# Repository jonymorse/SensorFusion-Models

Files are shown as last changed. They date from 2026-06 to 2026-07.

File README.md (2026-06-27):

# Sensor Fusion Models

ForgeCAD models and supporting scripts for the sensor fusion project's 3D
design work.

## Layout

```text
cad/
  sensor_fusion/  Active sensor fusion, PT3, GoPro, and RealSense CAD sources
  calibration/    Active thermal calibration target CAD source
  tests/          Printable fit/check coupons and their local helpers
  concepts/       Older concepts and exploratory designs

hardware_refs/    Imported STEP/F3D/3MF reference geometry
docs/             Design notes and requirements
outputs/
  previews/       Rendered preview images
  exports/        Generated CAD exports
archive/          Historical reports, tiny experiments, and superseded sources
scripts/          Utility scripts for snap-fit tuning workflows
```

`forgecad_work_2026-06-22/references/` is intentionally ignored. It is a local
copied reference bundle, not part of the cleaned source tree.

## Commands

```powershell
npm.cmd run check:coupon
npm.cmd run check:insert-coupon
npm.cmd run check:thermal
npm.cmd run check:realsense
npm.cmd run check:sensor-fusion
npm.cmd run check:gopro-stand
npm.cmd run studio
```

PowerShell script execution is disabled on this machine, so use `npm.cmd` and
`forgecad.cmd` rather than the `.ps1` shims.

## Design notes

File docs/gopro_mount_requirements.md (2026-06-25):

# GoPro-Compatible Mount Requirements

## Scope

Design a new, 3D-printable GoPro-compatible mount without modifying the thermal
calibration target. The first interface should be the accessory-side 3-prong
receiver that accepts the two folding fingers on a GoPro camera.

GoPro confirms that its ecosystem uses standard mounting fingers and offers
adapters between mounting fingers and 1/4-20 equipment, but GoPro does not
publish a dimensioned finger-interface drawing.

Official references:

- https://gopro.com/en/pl/shop/mounts-accessories/mounting-finger-adapter/ABTFR-001.html
- https://gopro.com/en/at/shop/mounts-accessories/tripod-adapters/ABQRT-003.html

The dimensions below are de facto compatibility dimensions cross-checked from
measured examples and a parametric OpenSCAD implementation. They are not an
official GoPro mechanical standard.

Measured and parametric references:

- https://www.instructables.com/GoPro-clamp-mount-for-multiple-angles-with-one-cam/
- https://github.com/ridercz/GoProScad/blob/master/GoPro.scad

## Interface Datasheet

| Feature | Nominal | First-print target | Notes |
|---|---:|---:|---|
| Finger thickness | 3.0 mm | 3.0 mm | Both 2-prong and 3-prong fingers |
| Mating gap | 3.5 mm | 3.4-3.5 mm | Includes practical print clearance |
| Pivot screw | M5 | M5 x 0.8 | Original GoPro thumb screw preferred |
| Pivot hole | 5.0 mm | 5.3 mm | Tune from 5.1-5.5 mm by test print |
| Rounded finger-end diameter | 15.0 mm | 15.0 mm | Radius 7.5 mm |
| Finger/leg height | 17.0 mm | 17.0 mm | Do not reduce below 15 mm |
| Base thickness | 3.0 mm | 3.5-4.0 mm | Increased for FDM strength |
| Minimum mount width | 15.0 mm | 20.0 mm | Width perpendicular to finger stack |
| 2-prong stack depth | 9.5 mm | 9.5 mm | 3 + 3.5 + 3 |
| 3-prong interface depth | 16.0 mm | 16.0 mm | 3 + 3.5 + 3 + 3.5 + 3 |
| Nut-capture allowance | 3.0 mm | Optional | Raises 3-prong base depth to 19 mm |

For a 17 mm leg and 3 mm base, the pivot axis is 12.5 mm above the bottom of
the base, or 9.5 mm above the base's top face.

## Parametric Controls

The ForgeCAD model should expose these controls:

- `Interface`: 3-prong receiver or 2-prong arm.
- `Finger Thickness`: default 3.0 mm, range 2.8-3.2 mm.
- `Mating Gap`: default 3.5 mm, range 3.2-3.8 mm.
- `Pivot Hole Diameter`: default 5.3 mm, range 5.0-5.6 mm.
- `Finger Height`: default 17 mm, range 15-22 mm.
- `Base Width`: default 20 mm, minimum 15 mm.
- `Base Thickness`: default 4 mm, minimum 3 mm.
- `Nut Capture`: none, square M5 nut, or hex M5 nut.

Do not scale the entire interface uniformly. Finger width, mating clearance,
and pivot-hole clearance need independent tolerances.

## Structural Requirements

- Add at least a 2 mm root fillet or equivalent tapered gusset at each finger.
- Keep at least 2.0 mm of material around the pivot hole.
- Avoid sharp internal corners at the finger-to-base transition.
- Use the original metal M5 thumb screw rather than a printed screw.
- Add a mechanical safety tether for vehicle, helmet, overhead, or outdoor use.
- Keep the camera center of mass as close to the pivot as the application allows.
- Treat the mount as a prototype until it passes fit, torque, vibration, and drop tests.

## Bambu A1 Print Requirements

- PLA+ is acceptable for fit prototypes; PETG or ASA is preferred for outdoor,
  hot-car, vibration, or impact exposure.
- Use a 0.4 mm nozzle with at least four walls/perimeters.
- Use 0.16-0.20 mm layers around the interface.
- Use at least 40% infill; use more for long arms or high-vibration mounts.
- Orient the part so layer lines run along the finger length, not across the
  finger roots. Side printing will usually require support but is stronger.
- Avoid aggressive cooling on PETG/ASA finger roots to preserve layer adhesion.

## Validation Coupon

Before printing the full mount, print a coupon containing only:

- The 3-prong finger interface.
- A 5.3 mm through-hole.
- One 3.4 mm gap and one 3.5 mm gap option.
- The 15 mm rounded finger ends.

Acceptance criteria:

- Camera fingers insert by hand without forcing or visible spreading.
- The M5 thumb screw passes through without drilling.
- The joint clamps firmly and holds angle without wobble.
- Fingers show no whitening, cracking, or delamination after ten clamp cycles.
- The camera can be removed without tools other than the normal thumb screw.

## Decisions Needed Before Full Geometry

- Base attachment: flat screw-down plate, adhesive base, clamp, 1/4-20 socket,
  tripod adapter, or custom device interface.
- Camera model and expected payload.
- Required tilt range and whether the joint must rotate continuously.
- Indoor prototype or outdoor/action use.
- Original GoPro thumb screw or generic M5 hardware.

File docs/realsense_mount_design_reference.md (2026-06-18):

# RealSense Mount Design Reference

This document is the measurement and packaging reference for the redesigned
RealSense / PureThermal / USB-C hub mount.

It is meant to answer two questions before CAD work starts:

1. What hardware is definitely part of the assembly?
2. What dimensions are confirmed vs. still need to be measured?

## Assembly Scope

Current known components:

- Intel RealSense Depth Camera `D435i`
- PureThermal 3 FLIR Lepton Smart I/O Board
- ORICO USB-C hub PCB from the `ORICO-XHJ2U2C-G2`
- Optional rear mounting interface
  - original design: GoPro-style prongs
  - current alternate mode: stand legs

## Confirmed Dimensions

### Intel RealSense D435i

Source status: `confirmed from official Intel / RealSense documentation`

| Item | Value | Notes |
| --- | --- | --- |
| Overall width | `90 mm` nominal | D435 / D435i body width |
| Overall height | `25 mm` nominal | cross-section height |
| Overall depth | `25 mm` nominal | housing depth |
| Weight | `72 g` in 2018 datasheet, `75 g` in later RealSense datasheet | small revision difference between source editions |
| Mounting holes | `2x M3` | mechanical drawing calls out `2X M3 mounting point` |
| Max screw insertion depth | `3 mm` | called out in mechanical drawing |
| Mount hole spacing | `45 mm` | center-to-center spacing shown in the mechanical drawing top view |
| Stereo baseline | `50 mm` | useful reference, but not the mount-hole spacing |
| IMU | `6DoF` | D435i-specific feature |
| Depth FOV (HD) | `87 deg x 58 deg` | from product family table |

### D435i Mounting Notes

- Use `M3` screws only for the D435i mount points.
- Treat `3 mm` as the maximum safe thread engagement into the camera body.
- The `45 mm` value is the relevant bracket dimension for the two camera mount
  points.
- The `50 mm` value shown in the mechanical drawing is the stereo baseline, not
  the screw-hole spacing.
- Rear USB-C cable clearance must be preserved in the final bracket layout.

### PureThermal 3 FLIR Lepton Smart I/O Board

Source status: `confirmed from official GroupGets datasheet / mechanical drawing`

| Item | Value | Notes |
| --- | --- | --- |
| Overall board width | `25.8 mm` | mechanical drawing |
| Overall board height | `28.9 mm` | mechanical drawing |
| Mounting holes | `4` | one near each rounded corner |
| Mounting hole diameter | `2.2 mm` | drawing callout `diameter 2.2` |
| Mounting hole X spacing | `20.7 mm` | center-to-center from left to right mounting holes |
| Mounting hole Z spacing | `23.9 mm` | center-to-center from top to bottom mounting holes |
| Board tolerance | `+/- 0.2 mm` | stated on the mechanical drawing |
| Board thickness / section reference | `1.6 mm` | shown on side-view drawing; interpreted as PCB thickness |
| USB connector | `USB-C` | edge-mounted on one side of the board |
| Breakout edges | `0.1 in / 2.54 mm` pitch through-holes | per datasheet feature list |

### PureThermal 3 Mounting Notes

- The corner mounting pattern is much smaller than the D435i pattern, which
  means the PureThermal 3 can likely fit well inside the D435i mounting-height
  envelope.
- The mounting holes are `2.2 mm`, so they are suited to approximately `M2`
  class hardware or clearance around similarly sized fasteners.
- The board includes an edge-mounted `USB-C` connector and side breakout rows,
  so the bracket should avoid trapping cable insertion or access to edge I/O.
- The Lepton socket occupies the central top-face area, so front-side keep-outs
  around the sensor module and its viewing path are important.

### ORICO USB-C Hub PCB

Source status: `exact product identified; external enclosure confirmed from official ORICO documentation; bare PCB dimensions provided from direct user measurement and redesign notes`

Exact product in use:

- Retail description: `ORICO 10Gbps USB-C Hub, 4-Port Zinc Alloy USB 3.2 Splitter with 2 USB-A & 2 USB-C Ports`
- Official ORICO model: `ORICO-XHJ2U2C-G2`

Confirmed external product details:

| Item | Value | Notes |
| --- | --- | --- |
| Product model | `ORICO-XHJ2U2C-G2` | official ORICO page |
| Housing material | `Zinc Alloy + PC` | official ORICO page |
| Input | `USB-C` | official ORICO page |
| Outputs | `2x USB-A, 2x USB-C` | official ORICO page |
| Transfer rate | `10 Gbps` | official ORICO page |
| Cable | `USB-C to USB-C, 0.5 m / 1 m` | official ORICO page |
| External housing size | `56.9 x 56.9 x 20.7 mm` | official ORICO page |
| Alternate retail size listing | `2.24 x 2.24 x 0.81 in` | Amazon listing; effectively the same size after unit conversion |

Confirmed PCB and mounting details:

| Item | Value | Notes |
| --- | --- | --- |
| PCB size | `51.0 x 51.0 mm` | from direct measurement / redesign notes |
| PCB thickness | `~1.6 mm` | from direct measurement / redesign notes |
| Mounting holes | `4` | one near each corner |
| Hole diameter | `2.4 mm to 2.6 mm` measured | design assumption `2.5 mm` |
| Hole center inset from edges | `~4.0 mm` | measured `~3.94 mm`, use `4.0 mm` for CAD |
| Hole spacing | `43.0 x 43.0 mm` | center-to-center |
| Hole centers | `(4,4), (47,4), (4,47), (47,47)` mm | using lower-left board corner as origin |
| Recommended PCB pocket | `51.8 x 51.8 mm` | includes clearance |
| Pocket clearance per side | `~0.4 mm` | from redesign notes |

### ORICO USB-C Hub Mounting Notes

- The official `56.9 x 56.9 x 20.7 mm` dimension is for the complete hub
  enclosure, not the bare PCB.
- The bare PCB is now dimensioned well enough to drive CAD for a replacement
  bottom shell or bracket interface.
- The hub has one upstream `USB-C` input and four downstream ports, so
  connector orientation and cable bend relief will be major layout drivers.
- A `51.8 x 51.8 mm` support pocket with `0.4 mm` clearance per side is the
  current recommended starting point.
- The replacement bottom shell should preserve the original screw geometry, port
  alignment, and PCB orientation so the stock clear top cover still fits.

## Needs Measurement

These items are part of the design, but I do not yet have every packaging
detail confirmed in-repo.

### USB-C PCB Hub

Still useful to confirm during shell redesign:

- boss/standoff height required to match the original enclosure stack
- exact screw head diameter and recess depth
- connector keep-out zones relative to the bare PCB
- solder-joint and underside component clearance depth
- whether the custom bottom shell should fully guard the sides or stay minimal

## Design Implications From Current Data

### D435i

- The camera is not the main height driver by itself; at `25 mm` tall it is
  relatively compact.
- The `45 mm` mount-hole spacing is close to the current CAD model's `45 mm`
  assumption, which is a good sign.
- Because the screw spec is `M3` with only `3 mm` max insertion depth, the
  bracket should avoid deep engagement assumptions or long screws bottoming out.

### PureThermal 3

- The PureThermal 3 board is small enough that it should not drive the overall
  mount height by itself.
- Its `20.7 mm x 23.9 mm` hole pattern makes screw-mounting much more attractive
  than long retainer rails.
- Because the board is only `25.8 mm x 28.9 mm`, it should be possible to place
  it within the same vertical envelope as the D435i mounting zone if desired.
- The `USB-C` edge and Lepton optical path should be treated as hard keep-out
  zones when shaping guards or protective walls.

### ORICO USB-C Hub

- The official product envelope is only moderately smaller than the current
  plate width, so this hub may still be one of the main packaging drivers.
- The measured `51.0 x 51.0 mm` PCB with a `43.0 mm` square hole pattern is now
  specific enough to support a proper shell redesign.
- This is the part most likely to determine whether the redesign uses
  screw-mounted shell capture, a pocketed cradle, or a guarded clamp strategy.

### Overall Mount Strategy

Because the D435i, PureThermal 3, and ORICO hub PCB all now have usable
mounting references, the redesign should strongly consider:

- screw-mounted boards instead of long rail retainers
- explicit standoffs or bosses
- controlled cable-clearance zones
- a separate decision about whether the GoPro interface is integrated or modular

## Open Questions

- Which exact PureThermal 3 board revision are we mounting?
- What boss/standoff height is required to reproduce the original ORICO shell's
  PCB stack-up under the reused clear top cover?
- What are the exact connector keep-out zones on the ORICO PCB relative to the
  mounting-hole origin?
- Should the GoPro-style rear interface be built into the main bracket or become
  a removable secondary part?
- Is the preferred redesign priority `smallest`, `cleanest`, `most rugged`, or
  some mix of those?

## Sources

- Intel RealSense D400 Series datasheet:
  https://cdrdv2-public.intel.com/841984/Intel-RealSense-D400-Series-Datasheet.pdf
- RealSense D435i product page:
  https://realsenseai.com/products/depth-camera-d435i/
- RealSense D400 Series datasheet, later revision:
  https://www.realsenseai.com/wp-content/uploads/2023/10/Intel-RealSense-D400-Series-Datasheet-September-2023.pdf
- GroupGets PureThermal 3 product page:
  https://groupgets.com/products/purethermal-3
- GroupGets PureThermal 3 datasheet:
  https://media.digikey.com/pdf/Data%20Sheets/GroupGets%20PDFs/PURETHERMAL-3_Rev2_Oct2022.pdf
- SparkFun PureThermal 3 listing:
  https://www.sparkfun.com/purethermal-3-flir-lepton-smart-i-o-board.html
- ORICO product page for the compact zinc alloy hub:
  https://www.orico.cc/index/product/detail/3473.html
- Amazon listing matching the retail description:
  https://www.amazon.com/ORICO-Splitter-High-Speed-Extender-Desktops/dp/B0FDB3WV1K
- Newegg listing with the matching ORICO model:
  https://www.newegg.com/p/0J2-001S-001Z6

## Source Notes

- Overall D435i body dimensions come from the D400 Series datasheet mechanical
  dimensions table.
- The `2x M3`, `45 mm` spacing, and `3 mm` max insertion depth values come from
  the D435/D435i mechanical drawing figure in the Intel datasheet.
- The later RealSense-hosted datasheet revision reports slightly tighter
  min/nominal/max dimensional tolerances and a `75 g` nominal weight; the core
  package size remains effectively the same for bracket design.
- The PureThermal 3 `25.8 mm x 28.9 mm` form factor is stated in the GroupGets
  datasheet feature list and in distributor product listings.
- The PureThermal 3 mounting-hole count, `2.2 mm` hole diameter, and
  `20.7 mm x 23.9 mm` hole spacing come from the mechanical drawing page in the
  GroupGets PureThermal 3 datasheet.
- The `1.6 mm` value is shown in the side-view mechanical drawing and is treated
  here as the PCB thickness reference.
- The ORICO model number `ORICO-XHJ2U2C-G2` and external dimensions
  `56.9 x 56.9 x 20.7 mm` come from ORICO's official product page.
- The Amazon size listing `2.24 x 2.24 x 0.81 in` is consistent with the
  official ORICO metric dimensions after unit conversion.
- The ORICO bare PCB values in this document come from direct user measurement
  and redesign notes: `51.0 x 51.0 mm` PCB, `2.5 mm` design hole diameter,
  `4.0 mm` hole-center inset, `43.0 x 43.0 mm` hole spacing, and a recommended
  `51.8 x 51.8 mm` support pocket.

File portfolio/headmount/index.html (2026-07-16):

Jonathan Morse (https://jonymorse.com)

Loading 3D geometry…

# Meta Quest 3S mount

A Meta Quest 3S mount with a GoPro-compatible attachment for cameras and sensors.

Drag to rotate · Scroll to zoom

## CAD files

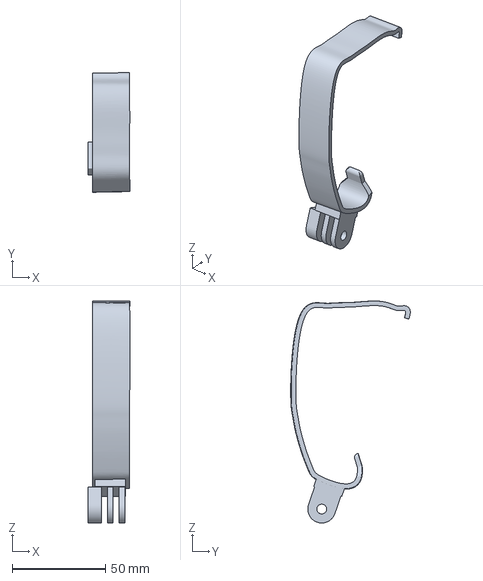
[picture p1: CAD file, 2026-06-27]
hardware_refs/3dmodels/quest3s-mount.3mf
22.4 x 64.3 x 119.3 mm

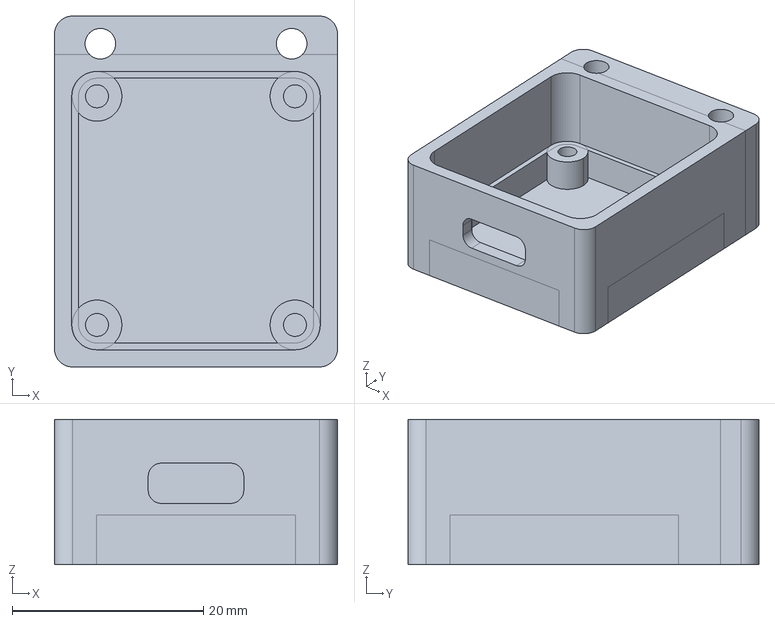
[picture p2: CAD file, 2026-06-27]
hardware_refs/purethermal_tray_only.step
29.6 x 36.7 x 15.2 mm

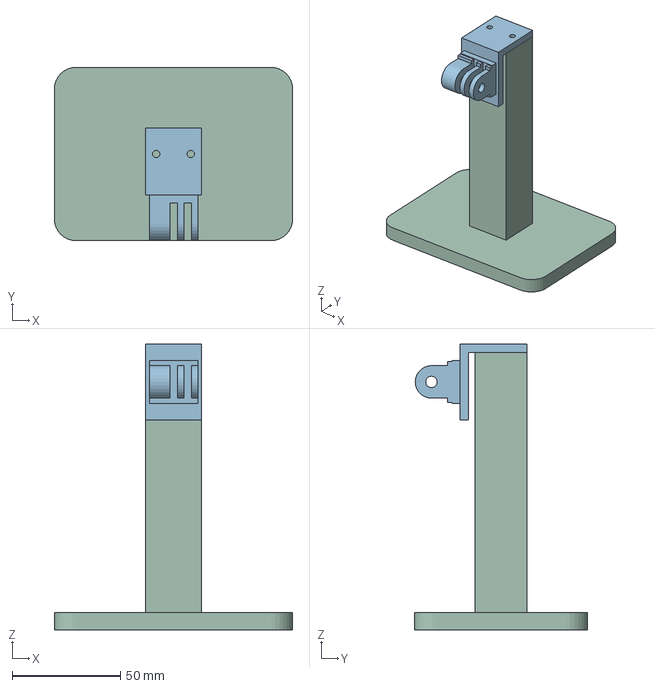
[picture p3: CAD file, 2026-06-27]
outputs/exports/gopro_camera_stand.3mf
110.0 x 80.0 x 132.0 mm
Camera Stand
Removable GoPro Bracket

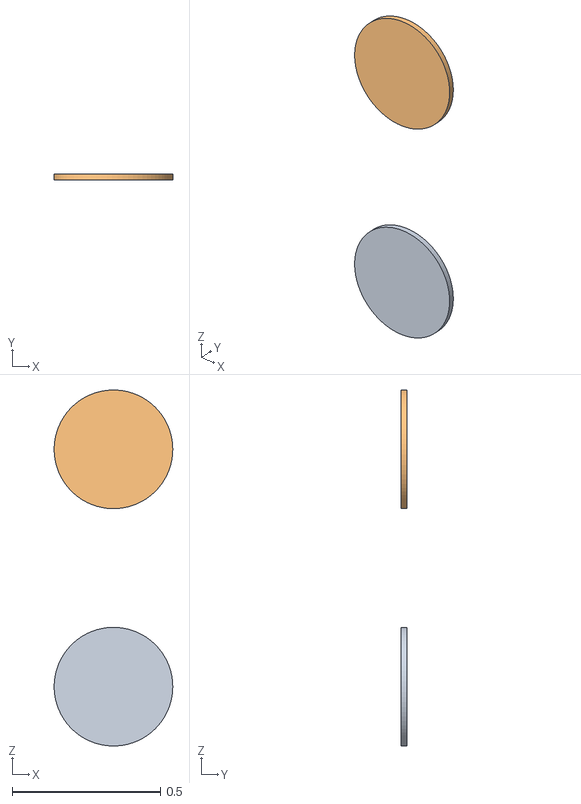
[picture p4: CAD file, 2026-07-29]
portfolio/assembly-viewer/models/02_front_membranes.obj
0.4 x 0.02 x 1.20

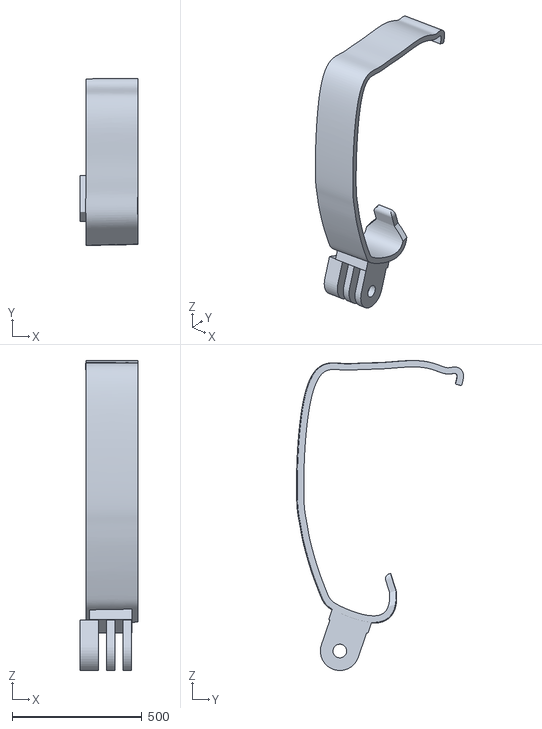
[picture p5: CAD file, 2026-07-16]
portfolio/headmount/assets/mq3s-mount-base.stl
224.3 x 643.0 x 1193.0

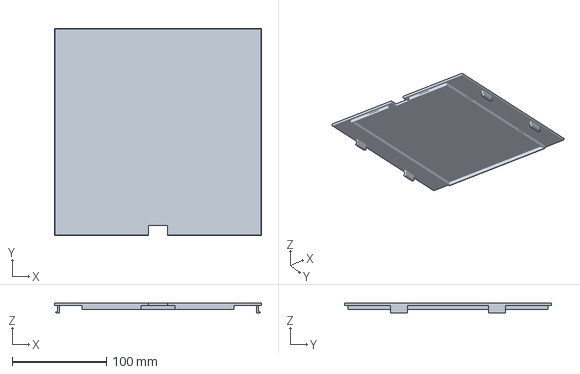
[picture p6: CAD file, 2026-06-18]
hardware_refs/3dmodels/backplate.3mf
220.0 x 220.0 x 11.0 mm

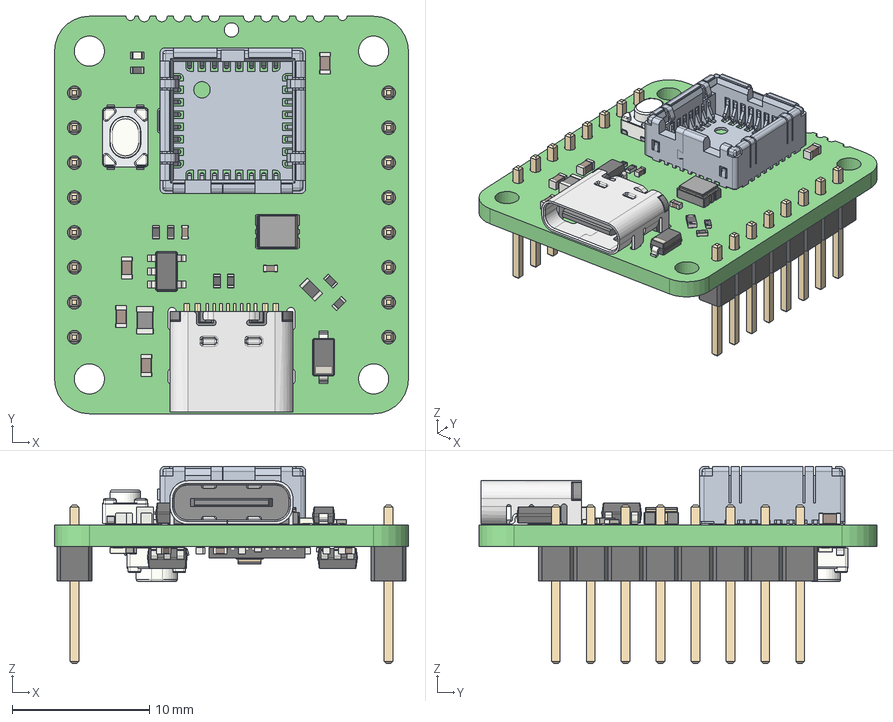
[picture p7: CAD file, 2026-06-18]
hardware_refs/PT3.step
25.8 x 28.9 x 14.3 mm
_autosave-PT3 PCB

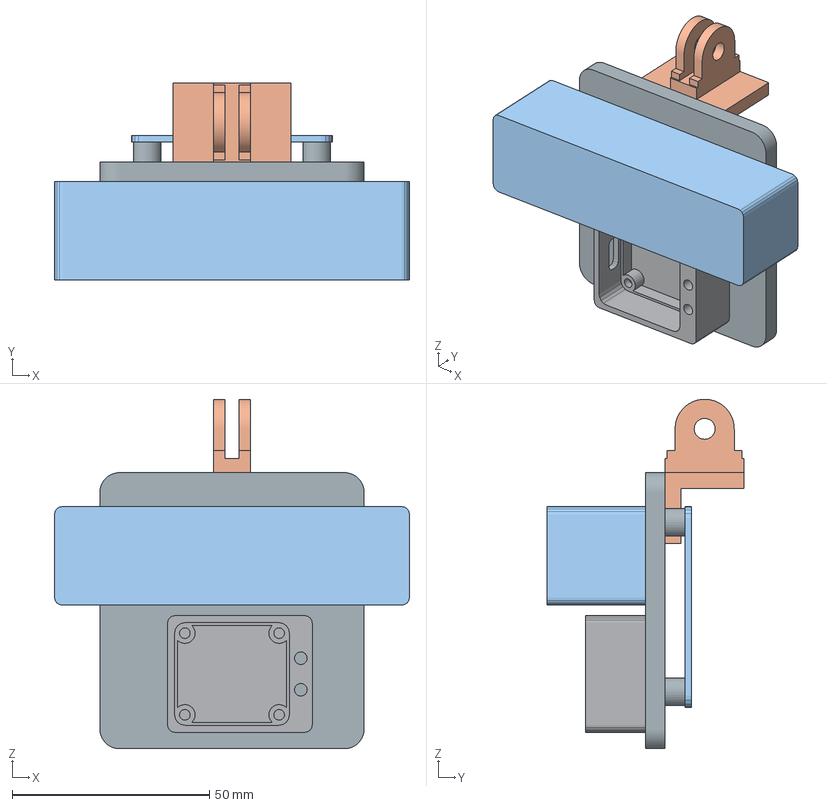
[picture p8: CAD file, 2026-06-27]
outputs/exports/sensor_fusion_mount.3mf
90.0 x 50.0 x 88.6 mm
Sensor Fusion Chassis
PureThermal 3 Tray
Detachable GoPro Adapter
Intel RealSense D435i Reference (mock)
ORICO USB-C Hub PCB Reference (mock)

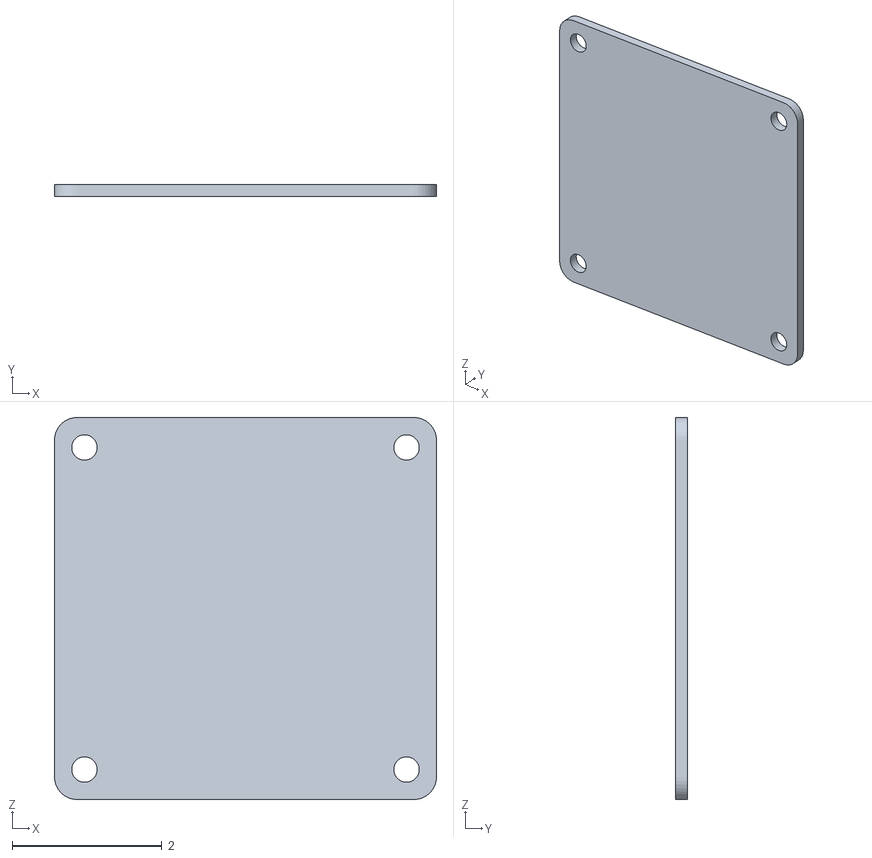
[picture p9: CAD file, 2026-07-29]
portfolio/assembly-viewer/models/05_orico_hub_pcb.obj
5.10 x 0.16 x 5.10

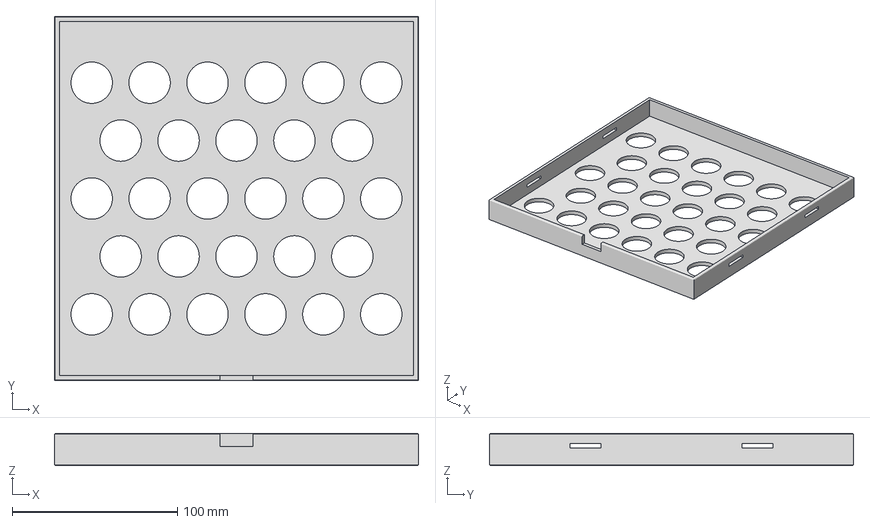
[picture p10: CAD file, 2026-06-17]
hardware_refs/3dmodels/thermal_calibration_target.3mf
220.0 x 220.0 x 19.5 mm

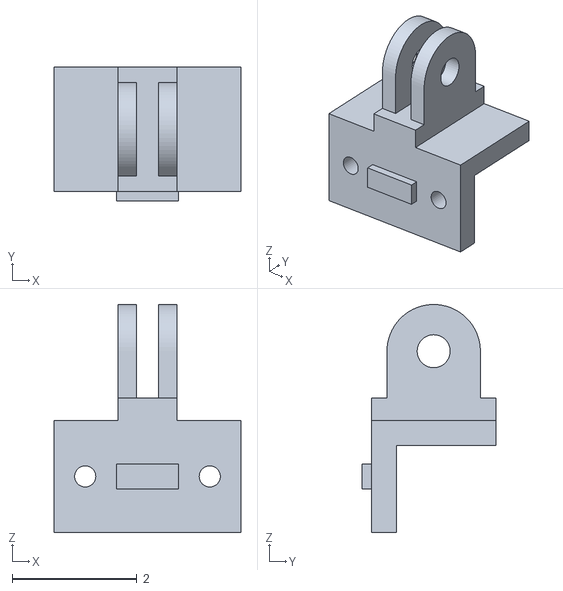
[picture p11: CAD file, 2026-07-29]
portfolio/assembly-viewer/models/04_gopro_adapter.obj
3.00 x 2.15 x 3.66

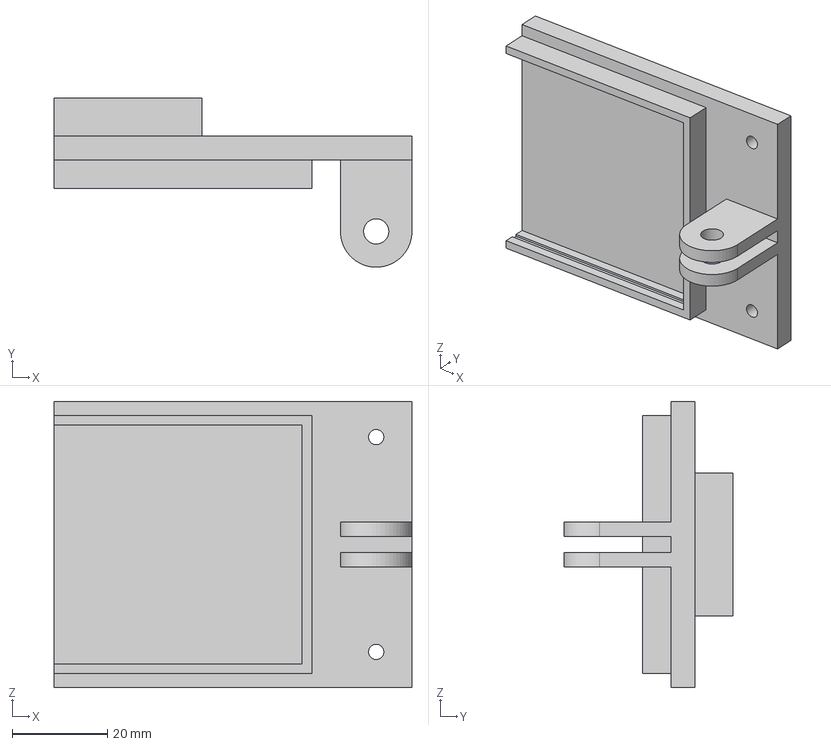
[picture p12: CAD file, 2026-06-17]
hardware_refs/3dmodels/GoPro Clamp_Clamp Top.step
75.0 x 35.5 x 60.0 mm

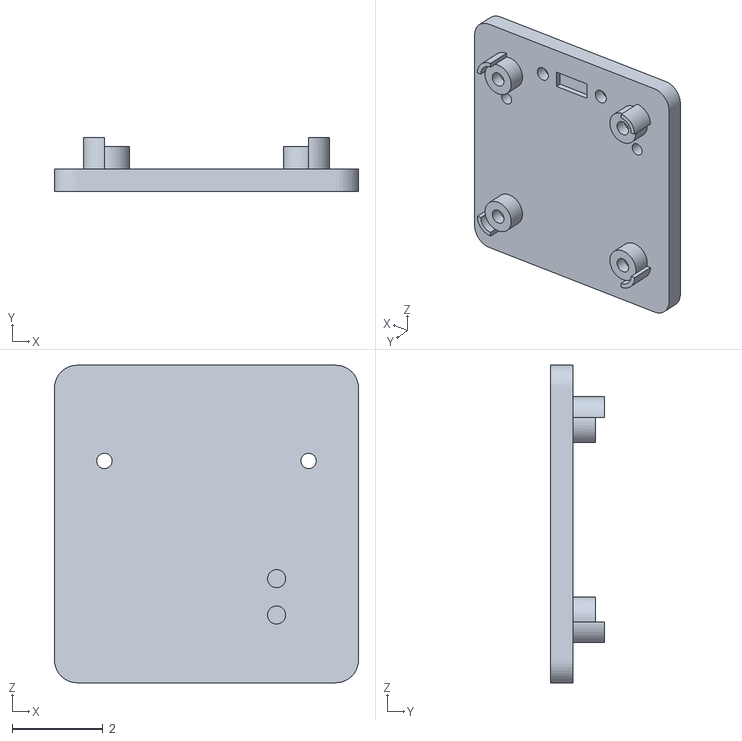
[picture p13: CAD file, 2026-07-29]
portfolio/assembly-viewer/models/01_sensor_chassis.obj
6.70 x 1.20 x 7.00

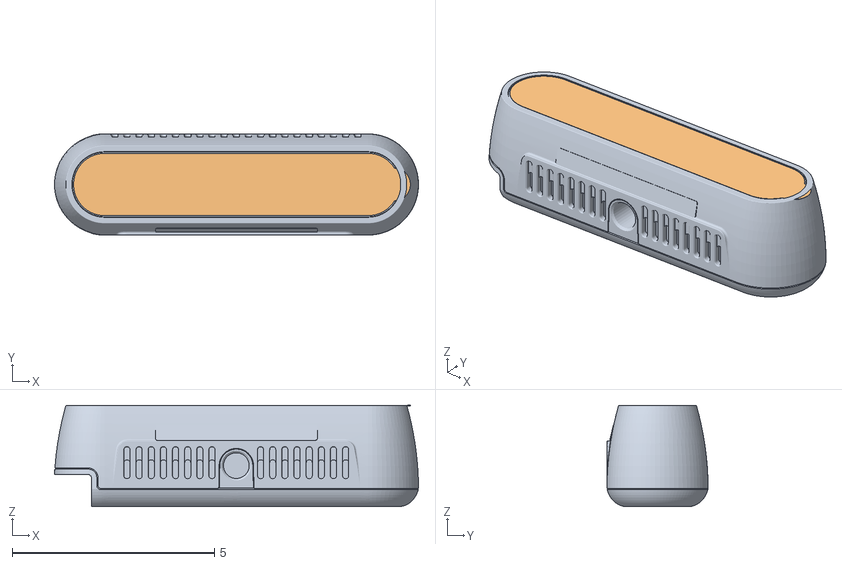
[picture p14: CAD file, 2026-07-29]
portfolio/assembly-viewer/models/06_realsense_d435i.obj
8.99 x 2.50 x 2.50

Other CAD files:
portfolio/assembly-viewer/models/03_pt3_slot_retainer.obj
portfolio/assembly-viewer/models/08_quest_mount.obj
portfolio/assembly-viewer/models/09_quest_3s.obj
hardware_refs/3dmodels/GoPro Clamp_Clamp Top.3mf
hardware_refs/GoPro Clamp_Clamp Top.f3d
hardware_refs/headmount.f3z

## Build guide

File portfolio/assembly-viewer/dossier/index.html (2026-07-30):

00 / XR Sensor Dossier

Designed & built by Jonathan Morse

# Make invisible sensing spatial.

A Quest-based prototyping platform for turning thermal, RGB, and depth streams into readable mixed-reality context.

PlatformMeta Quest 3S

SensorsThermal / RGB / Depth

StackUnity / Android / C++ / OpenXR

StatusWorking system / Active research



Thermal self-portrait / PT3 9 Hz

Open dossier

Hardware subsystem

## Physical sensor platform

Mounts, housings, targets, and assembly details that make external sensing repeatable on a Quest headset.

Subsystem explorer

## Hardware

Physical parts designed, printed, assembled, and revised around the headset.

HW-01

### Quest Mount

Prototype

## Private settings

Local preview controls

×

GraphiteBaseline CarbonWarm / quiet SlateCool technical OliveSubdued field PaperResearch light

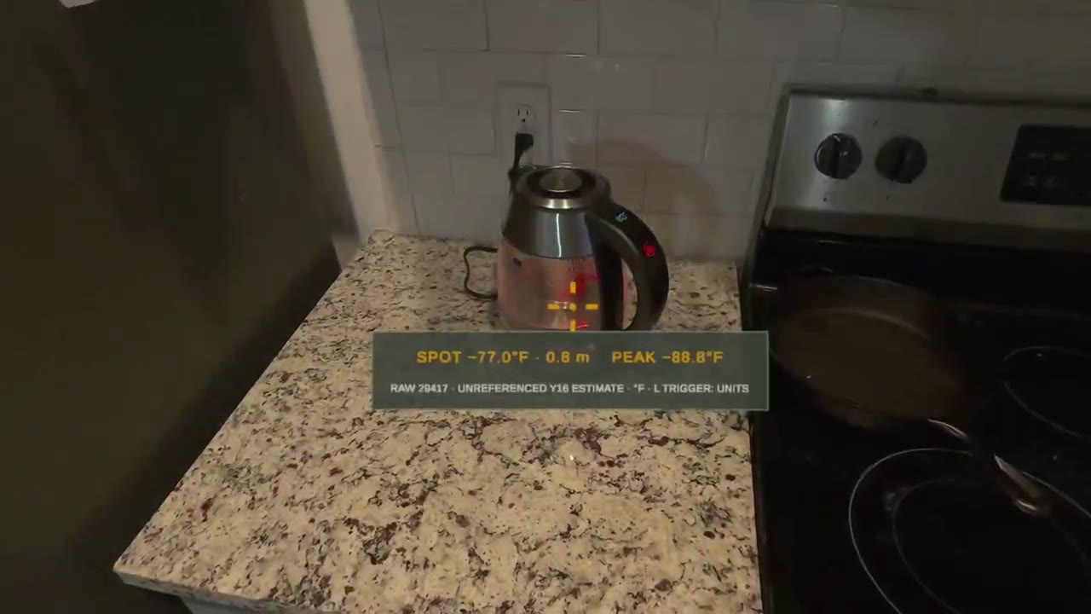
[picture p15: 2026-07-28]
portfolio/assembly-viewer/dossier/quest-captures/mode-01-boiling-water.jpg

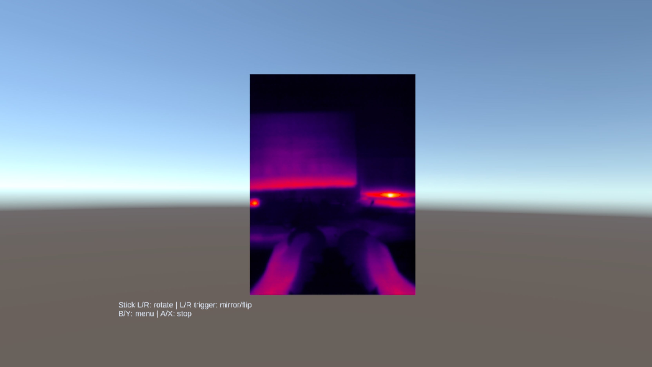
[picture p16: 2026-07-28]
portfolio/assembly-viewer/dossier/quest-captures/sensor-view-01.jpg

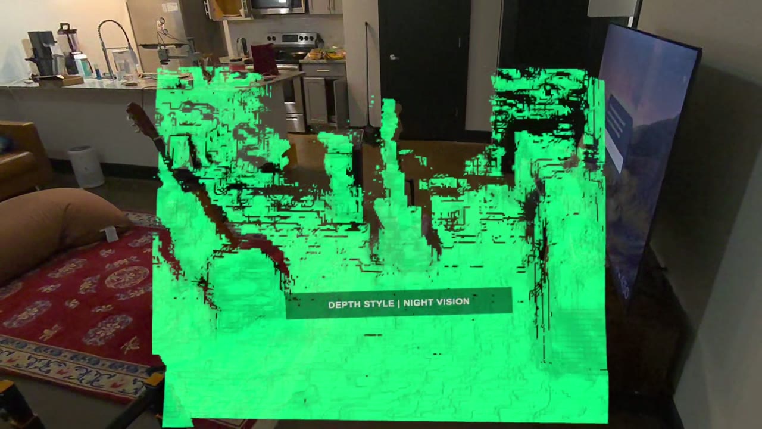
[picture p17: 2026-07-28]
portfolio/assembly-viewer/dossier/quest-captures/mode-03-depth-toggle.jpg

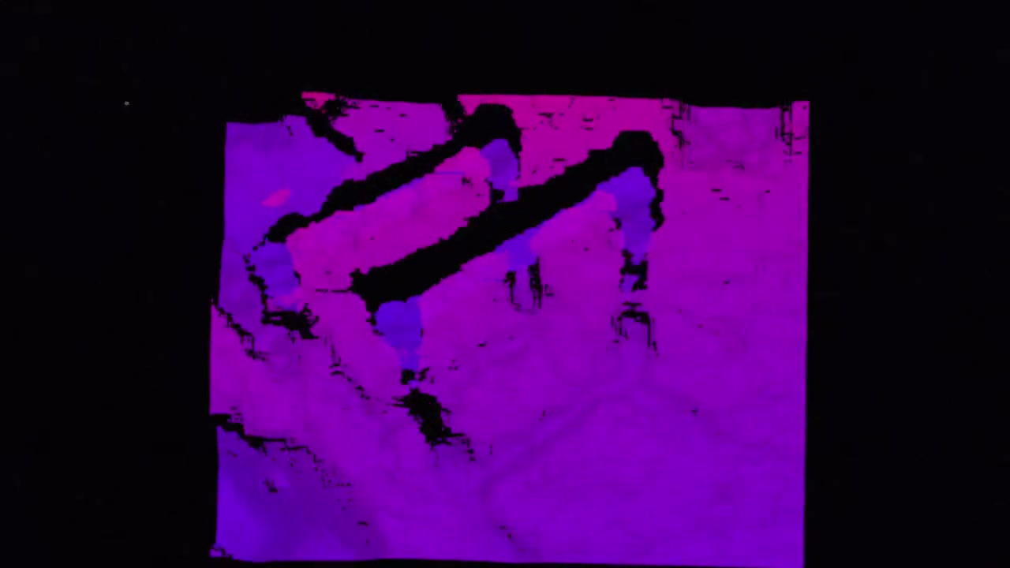
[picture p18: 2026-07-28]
portfolio/assembly-viewer/dossier/quest-captures/night-operation.jpg

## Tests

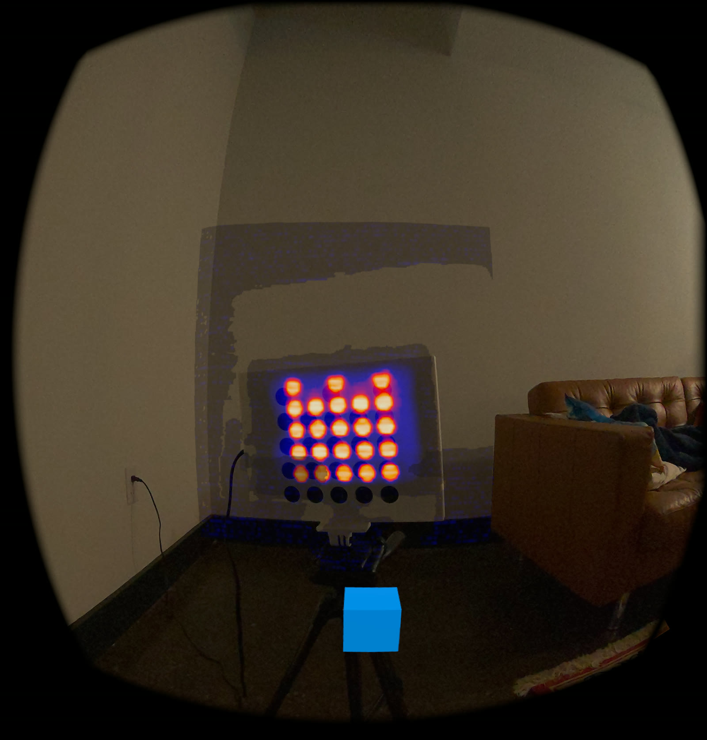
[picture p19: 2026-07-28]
portfolio/assembly-viewer/dossier/calibration/on-headset-end-to-end.jpg

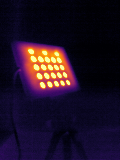
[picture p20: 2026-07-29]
portfolio/assembly-viewer/dossier/calibration/cover-poses/07-thermal.png

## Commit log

2026-06-17 Organize models into models folder
    [GoPro Clamp_Clamp Top.3mf, GoPro Clamp_Clamp Top.f3d, GoPro Clamp_Clamp Top.step]
2026-06-17 Add thermal calibration target 3mf
    [GoPro Clamp_Clamp Top.3mf, GoPro Clamp_Clamp Top.f3d, GoPro Clamp_Clamp Top.step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]
2026-06-18 added sensor mount
    [GoPro Clamp_Clamp Top.3mf, GoPro Clamp_Clamp Top.step, PT3.step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]
2026-06-27 reorganize forgecad repository
    [GoPro Clamp_Clamp Top.3mf, GoPro Clamp_Clamp Top.f3d, GoPro Clamp_Clamp Top.step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]
2026-06-27 added xport
    [gopro_camera_stand.3mf]
2026-07-16 Publish headmount portfolio
    [mq3s-mount-base.stl]
2026-07-27 Deploy sensor fusion assembly viewer
2026-07-27 Attach sensor assembly components
2026-07-27 Correct sensor orientation and mount attachment
2026-07-28 Update material-complete exploded assembly viewer
2026-07-28 Fix exploded floor and mount clearance
2026-07-28 Separate exploded mount components
2026-07-28 Tighten mobile assembly viewer
2026-07-28 Publish calibrated sensor-fusion dossier
2026-07-28 Refine calibration dossier flow
2026-07-28 Refine SensorFusionXR dossier
    Refine the Integration and Calibration case-study layouts, remove redundant UI and copy, and publish the dossier at /SensorFusionXR/.
2026-07-28 Add tasteful asset loading states
    Add delayed loading and failure states for dossier media and the interactive assembly model, including reduced-motion support.
2026-07-29 Rebuild calibration dossier as field session
2026-07-29 Redesign calibration session layout
2026-07-29 Refine calibration review and validation
    [01_sensor_chassis.obj, 02_front_membranes.obj, 03_pt3_slot_retainer.obj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]
2026-07-30 Tighten mobile viewer controls
